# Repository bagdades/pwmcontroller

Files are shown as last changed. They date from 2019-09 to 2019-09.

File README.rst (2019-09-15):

PWM Controller
==============

This repository contains the hardware design files (for use with KiCad) that
will create a PWM controller board. The intent here is to plug this in between
a motherboard 4-pin fan header and a powered fan splitter, like the Silverstone
CPF04 or Swiftech 8W-PWM-SPL-ST. The pwm signal is generated by the 555 timer
on the board and adjusted with the on pcb potentiometer, 12v fan power from
the motherboard is used solely for the DC/DC converter and 555 timer. No power
pins are connected on the output fan header.

A write up documenting this project's development can be found here:

https://blog.kortar.org/?p=437



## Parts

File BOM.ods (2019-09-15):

Manufacturer | Manufacturer Part Number | Designator | QTY | Description | Mouser Part Number
TI | NE555P | U2 | 1 | 555 Timer | 595-NE555P
Molex | 47053-1000 | J1,J2 | 2 | 4-pin PWM Fan Header | 538-47053-1000
ON Semiconductor/Fairchild | LM78L05ACZ | U1 | 1 | Fixed 5V linear regulator | 512-LM78L05ACZ
Bourns | PTV09A-4020S-B104 | RV1 | 1 | 100k Linear 1 turn pot | 652-PTV09A4020SB104
Yageo | CFR-25JR-52-4K7 | R2 | 1 | 4.7k Axial Resistor | 603-CFR-25JR-524K7
Yageo | CFR-25JR-52-1K | R1 | 1 | 1k Axial Resistor | 603-CFR-25JR-521K
Illinois Capacitor / CDE | 106RSS016M | C3 | 1 | 10uF Electrolytic Capacitor | 598-106RSS016M
Vishay/BC Components | K104K15X7RF53L2 | C4,C6 | 2 | .1uF Ceramic Capacitor | 594-K104K15X7RF53L2
ON Semiconductor/Fairchild | 1N4148 | D1,D2 | 2 | 1N4148 Diode | 512-1N4148
Vishay/BC Components | D103M29Z5UH6UJ5R | C1 | 1 | .01uF Ceramic Capacitor | 594-D103M29Z5UH6UJ5R
Vishay/BC Components | K471J15C0GF53L2 | C2 | 1 | 470pF Ceramic Capcitor | K471J15C0GF53L2
TI | SN74AHC1G14DBVR | U3 | 1 | Inverting Schmitt Trigger | 595-SN74AHC1G14DBVR
Nichicon | UVR2AR33MDD1TD | C5 | 1 | .33uF Electrolytic Capcacitor | 647-UVR2AR33MDD1TD

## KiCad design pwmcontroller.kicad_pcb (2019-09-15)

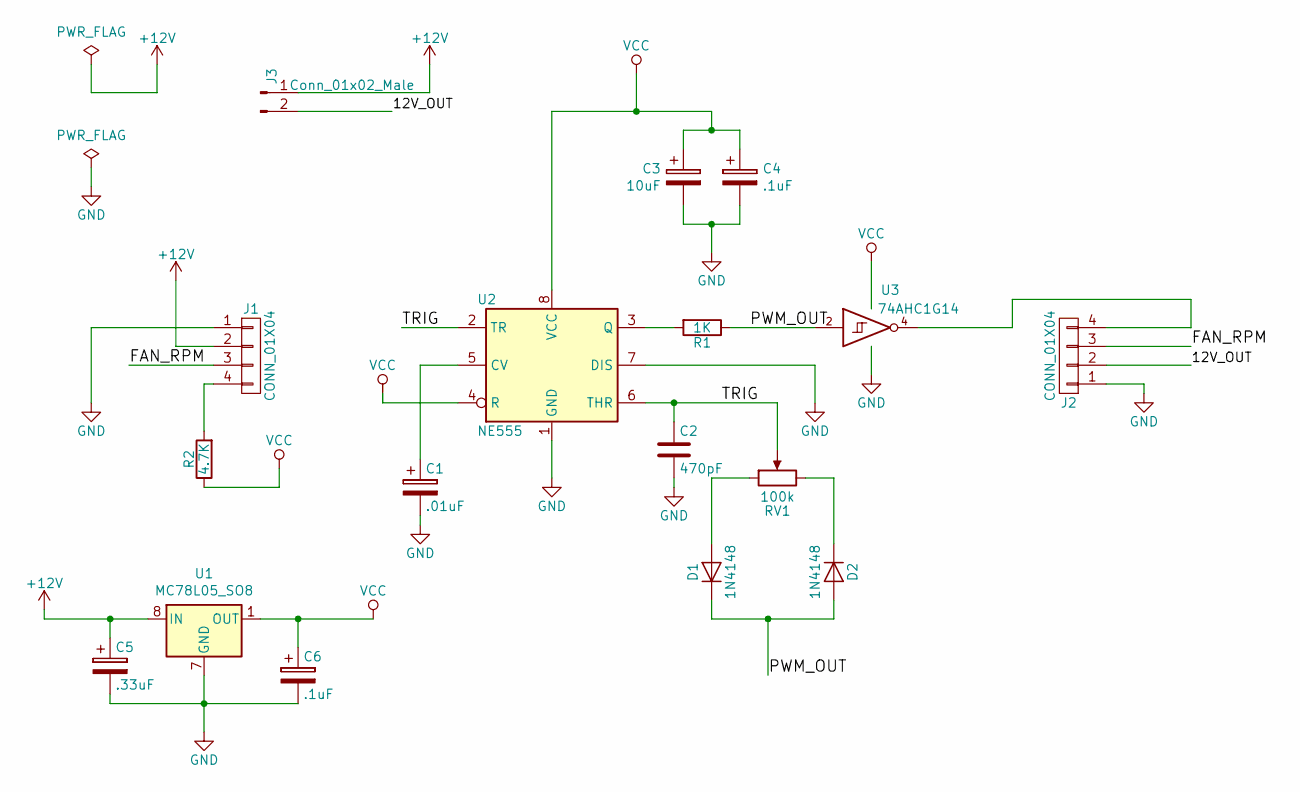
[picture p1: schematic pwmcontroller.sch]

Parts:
C1: .01uF; C_0805_2012Metric
C2: 470pF; C_0805_2012Metric
C3: 10uF; CP_Radial_D5.0mm_P2.50mm
C4, C6: .1uF; C_0805_2012Metric
C5: .33uF; CP_Radial_D5.0mm_P2.50mm
D1, D2: 1N4148; D_SOD-123
J1, J2: CONN_01X04; Molex_KK-254_AE-6410-04A_1x04_P2.54mm_Vertical
J3: Conn_01x02_Male; PinHeader_1x02_P2.54mm_Vertical
R1: 1K; R_0805_2012Metric
R2: 4.7K; R_0805_2012Metric
RV1: 100k; Potentiometer_Alpha_RD901F-40-00D_Single_Vertical_CircularH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
U1: MC78L05_SO8; SOIC-8_3.9x4.9mm_P1.27mm
U2: NE555; DIP-8_W7.62mm
U3: 74AHC1G14; SOT-23-5

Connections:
+12V: C5.1, J1.2, J3.1, U1.8 (IN)
/12V_OUT: J2.2, J3.2
/FAN_RPM: J1.3, J2.3
/PWM_OUT: D1.1 (K), D2.2 (A), R1.1, U3.2
/TRIG: C2.1, RV1.2, U2.2 (TR), U2.6 (THR)
GND: C1.2, C2.2, C3.2, C4.2, C5.2, C6.2, J1.1, J2.1, U1.2 (GND), U1.3 (GND), U1.6 (GND), U1.7 (GND), U2.1 (GND), U2.7 (DIS), U3.3 (GND)
unnamed: C1.1, U2.5 (CV)
unnamed: D1.2 (A), RV1.1
unnamed: D2.1 (K), RV1.3
unnamed: J1.4, R2.2
unnamed: J2.4, U3.4
unnamed: R1.2, U2.3 (Q)
VCC: C3.1, C4.1, C6.1, R2.1, U1.1 (OUT), U2.4 (R), U2.8 (VCC), U3.5 (VCC)

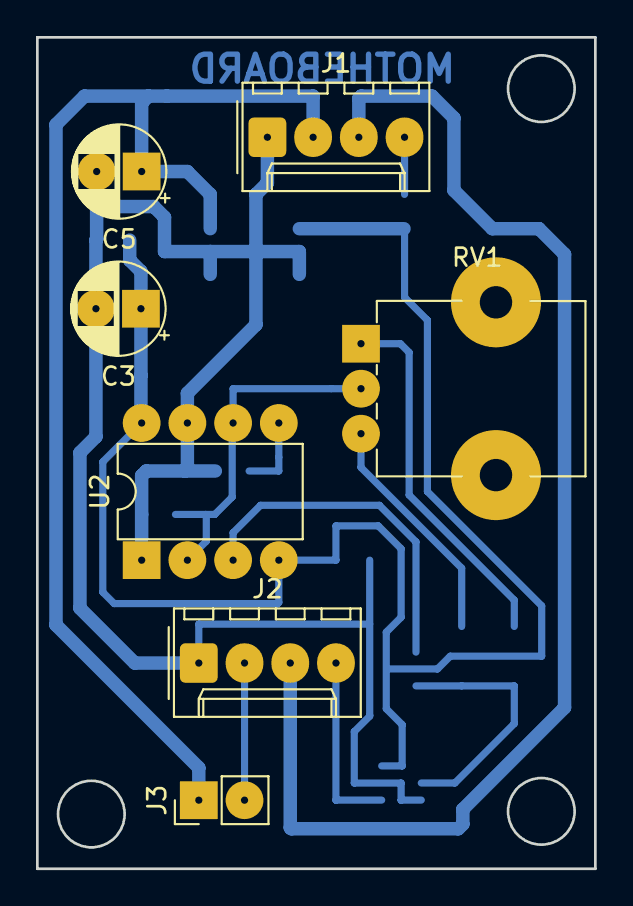
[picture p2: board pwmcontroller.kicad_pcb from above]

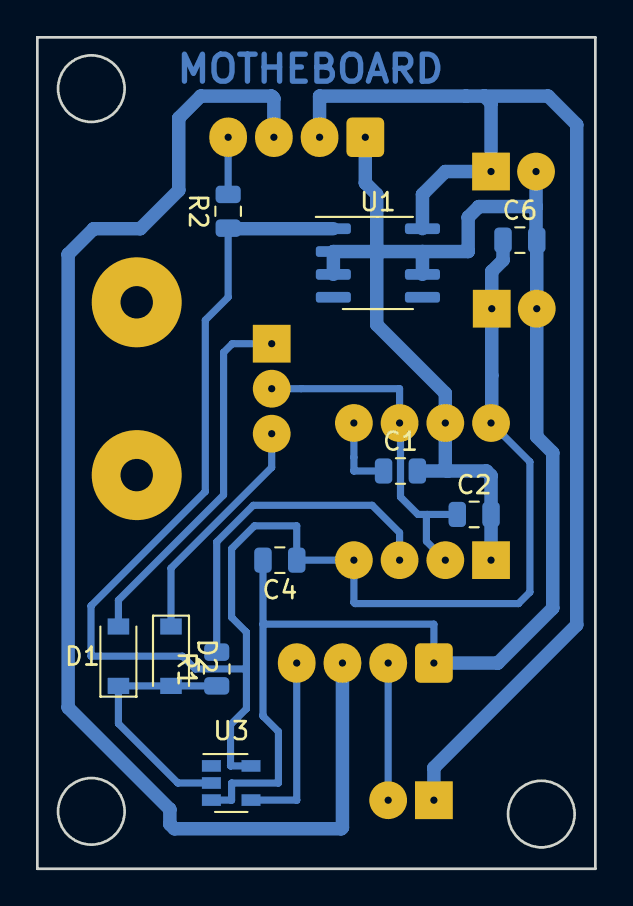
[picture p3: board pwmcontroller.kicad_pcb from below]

Board: 2 copper layers, 31.0 x 46.2 mm, 17 parts (10 on the bottom side), 13 nets.
